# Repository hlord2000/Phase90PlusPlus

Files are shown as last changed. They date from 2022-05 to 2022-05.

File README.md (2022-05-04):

# This is a modified and extended Phase90 pedal, intended to fit into a [1590BB enclosure](https://lovemyswitches.com/1590bb-enclosure-bare-aluminum-powder-coat/). Enjoy.

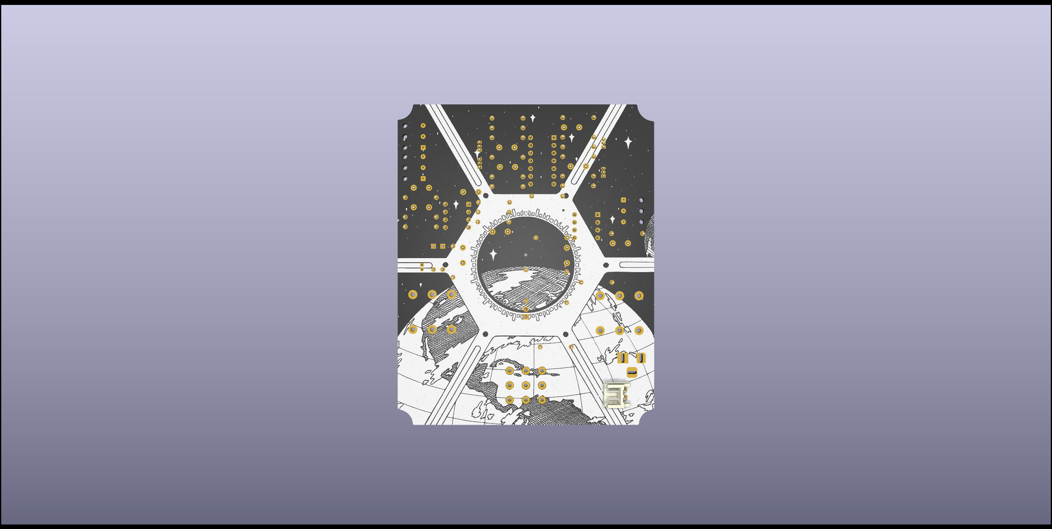
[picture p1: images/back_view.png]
Back View


## Interesting features
This pedal uses a software-controlled LFO [(StompLFO, a PIC microcontroller programmed by ElectricDruid)](https://electricdruid.net/product/stomplfo/) to generate a cool bunch of waveforms. The specific waveform is controlled with a potentiometer. An op-amp mixer is included on the output of the pedal, too, so that a musician can alter the mix of wet/dry tone. Finally, the traditional frequency potentiometer is included. This is a true bypass pedal.

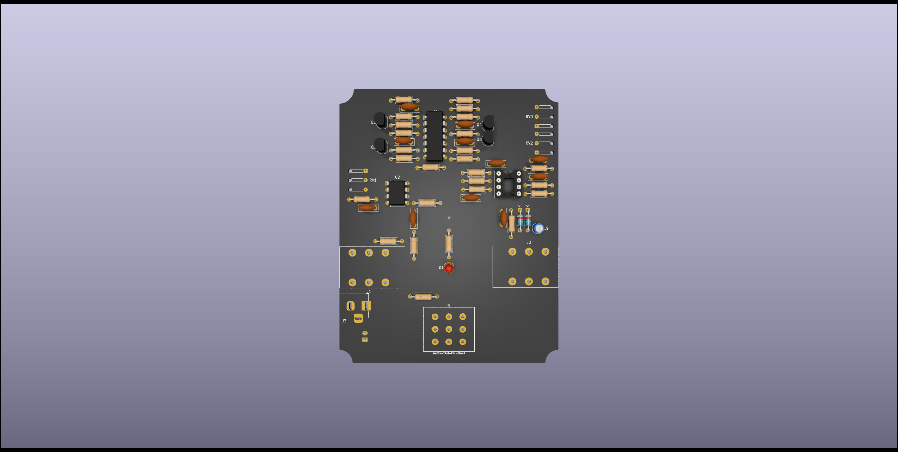
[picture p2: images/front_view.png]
Front View


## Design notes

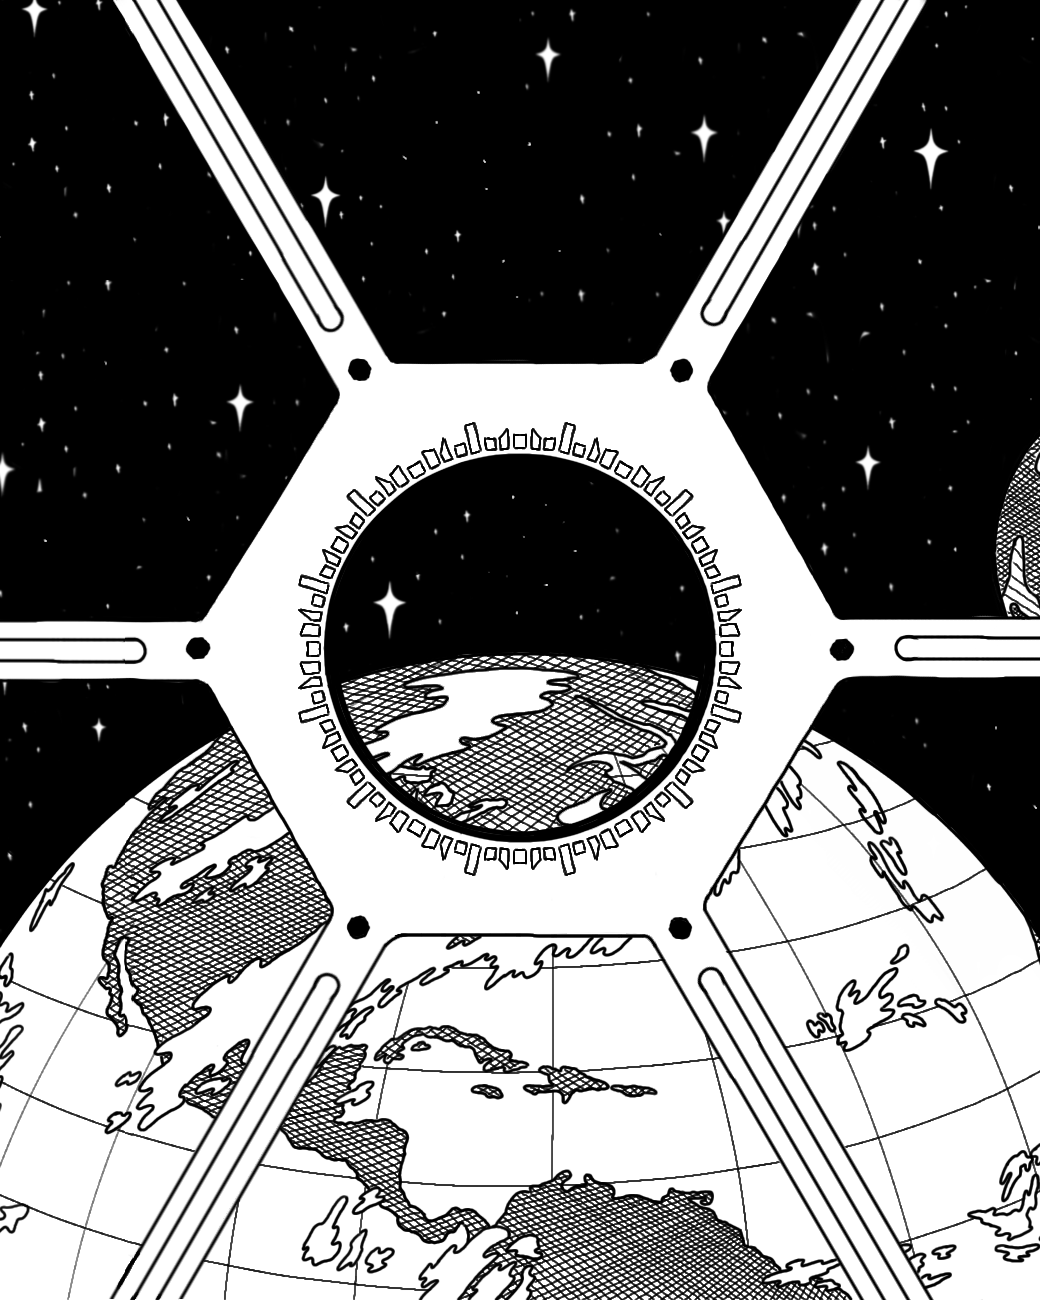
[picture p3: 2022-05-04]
images/art.png

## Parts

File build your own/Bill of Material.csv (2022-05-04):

Source: | C:\Users\Helmut Lord\Documents\Phase90++\phase90plusplus.kicad_sch
Date: | 5/4/2022 3:37:26 PM
Tool: | Eeschema (6.0.1)
Generator: | C:\Program Files\KiCad\6.0\bin\scripting\plugins/bom_csv_grouped_by_value_with_fp.py
Component Count: | 56
Ref | Qnty | Value | Cmp name | Footprint | Description | Vendor
BT1, | 1 | 9V DC | Battery_Cell | Connector_JST:JST_EH_S2B-EH_1x02_P2.50mm_Horizontal | Single-cell battery
C1, | 1 | 0.01u | C_Small | Capacitor_THT:C_Disc_D7.5mm_W2.5mm_P5.00mm | Unpolarized capacitor, small symbol
C2, C3, C4, C5, C6, C7, | 6 | 47n | C_Small | Capacitor_THT:C_Disc_D7.5mm_W2.5mm_P5.00mm | Unpolarized capacitor, small symbol
C8, | 1 | 4n7 | C_Small | Capacitor_THT:C_Disc_D7.5mm_W2.5mm_P5.00mm | Unpolarized capacitor, small symbol
C9, | 1 | 15u | C_Polarized_Small | Capacitor_THT:CP_Radial_D4.0mm_P1.50mm | Polarized capacitor, small symbol
C10, | 1 | 47nF | C_Small | Capacitor_THT:C_Disc_D7.5mm_W2.5mm_P5.00mm | Unpolarized capacitor, small symbol
C11, C12, | 2 | 100n | C_Small | Capacitor_THT:C_Disc_D7.5mm_W2.5mm_P5.00mm | Unpolarized capacitor, small symbol
D1, | 1 | LED | LED | LED_THT:LED_D3.0mm | Light emitting diode
D2, | 1 | 1N914 | 1N914 | Diode_THT:D_DO-35_SOD27_P7.62mm_Horizontal | 100V 0.3A Small Signal Fast Switching Diode, DO-35
D3, | 1 | Zener | D_Zener | Diode_THT:D_DO-35_SOD27_P7.62mm_Horizontal | Zener diode
J1, | 1 | InputJack | AudioJack3_Dual_Switch_1 | Connector_Audio:Jack_6.35mm_Neutrik_NRJ6HM-1_Horizontal | Audio Jack, Dual, 3 Poles (Stereo / TRS), Switched Poles (Normalling)
J2, | 1 | OutputJack | AudioJack3_Dual_Switch | Connector_Audio:Jack_6.35mm_Neutrik_NRJ6HM-1_Horizontal | Audio Jack, Dual, 3 Poles (Stereo / TRS), Switched Poles (Normalling)
J3, | 1 | Barrel_Jack_Switch | Barrel_Jack_Switch | Connector_BarrelJack:BarrelJack_Horizontal | DC Barrel Jack with an internal switch
LFO1, | 1 | STOMPLFO_DIP8 | STOMPLFO_DIP8 | Package_DIP:DIP-8_W7.62mm_Socket
Q1, Q2, Q3, Q4, | 4 | 2N7000 | BF245A | Package_TO_SOT_THT:TO-92_Inline | 50mA Id, 30V Vgs, N-Channel FET Transistor, TO-92
R1, R2, R3, R4, R6, R7, R8, R9, R21, R22, R23, R24, | 12 | 10K | R_Small_US | Resistor_THT:R_Axial_DIN0207_L6.3mm_D2.5mm_P10.16mm_Horizontal | Resistor, small US symbol
R5, R10, | 2 | 150K | R_Small_US | Resistor_THT:R_Axial_DIN0207_L6.3mm_D2.5mm_P10.16mm_Horizontal | Resistor, small US symbol
R11, R13, | 2 | 500k | R_Small_US | Resistor_THT:R_Axial_DIN0207_L6.3mm_D2.5mm_P10.16mm_Horizontal | Resistor, small US symbol
R12, | 1 | 500 | R_Small_US | Resistor_THT:R_Axial_DIN0207_L6.3mm_D2.5mm_P10.16mm_Horizontal | Resistor, small US symbol
R14, R15, R16, R17, | 4 | 24K | R_Small_US | Resistor_THT:R_Axial_DIN0207_L6.3mm_D2.5mm_P10.16mm_Horizontal | Resistor, small US symbol
R18, | 1 | 150k | R_Small_US | Resistor_THT:R_Axial_DIN0207_L6.3mm_D2.5mm_P10.16mm_Horizontal | Resistor, small US symbol
R19, | 1 | 370 | R_Small_US | Resistor_THT:R_Axial_DIN0207_L6.3mm_D2.5mm_P10.16mm_Horizontal | Resistor, small US symbol
R20, | 1 | 100K | R_Small_US | Resistor_THT:R_Axial_DIN0207_L6.3mm_D2.5mm_P10.16mm_Horizontal | Resistor, small US symbol
R25, R26, | 2 | 1K | R_Small_US | Resistor_THT:R_Axial_DIN0207_L6.3mm_D2.5mm_P10.16mm_Horizontal | Resistor, small US symbol
RV1, RV2, RV3, | 3 | 10k | R_Potentiometer_US | Connector_Wire:SolderWire-0.1sqmm_1x03_P3.6mm_D0.4mm_OD1mm_Relief | Potentiometer, US symbol
S1, | 1 | SWITCH-3PDT-PTH-STOMP | SWITCH-3PDT-PTH-STOMP | Switches:STOMP_SWITCH_3PDT | 3-Pole, Double-Throw (3PDT) Switch Three-pole, double-throw stomp switch. Drawn as three separate gates for schematic clarity. <h4>SparkFun Products</h4><ul><li>Used in <a href="https://www.sparkfun.com/products/13124">SparkFun Proto Pedal</a> (PRT-13124)</li></ul>
U1, | 1 | TL074 | TL074 | Package_DIP:DIP-14_W7.62mm | Quad Low-Noise JFET-Input Operational Amplifiers, DIP-14/SOIC-14
U2, | 1 | TL072 | TL072 | Package_DIP:DIP-8_W7.62mm | Dual Low-Noise JFET-Input Operational Amplifiers, DIP-8/SOIC-8

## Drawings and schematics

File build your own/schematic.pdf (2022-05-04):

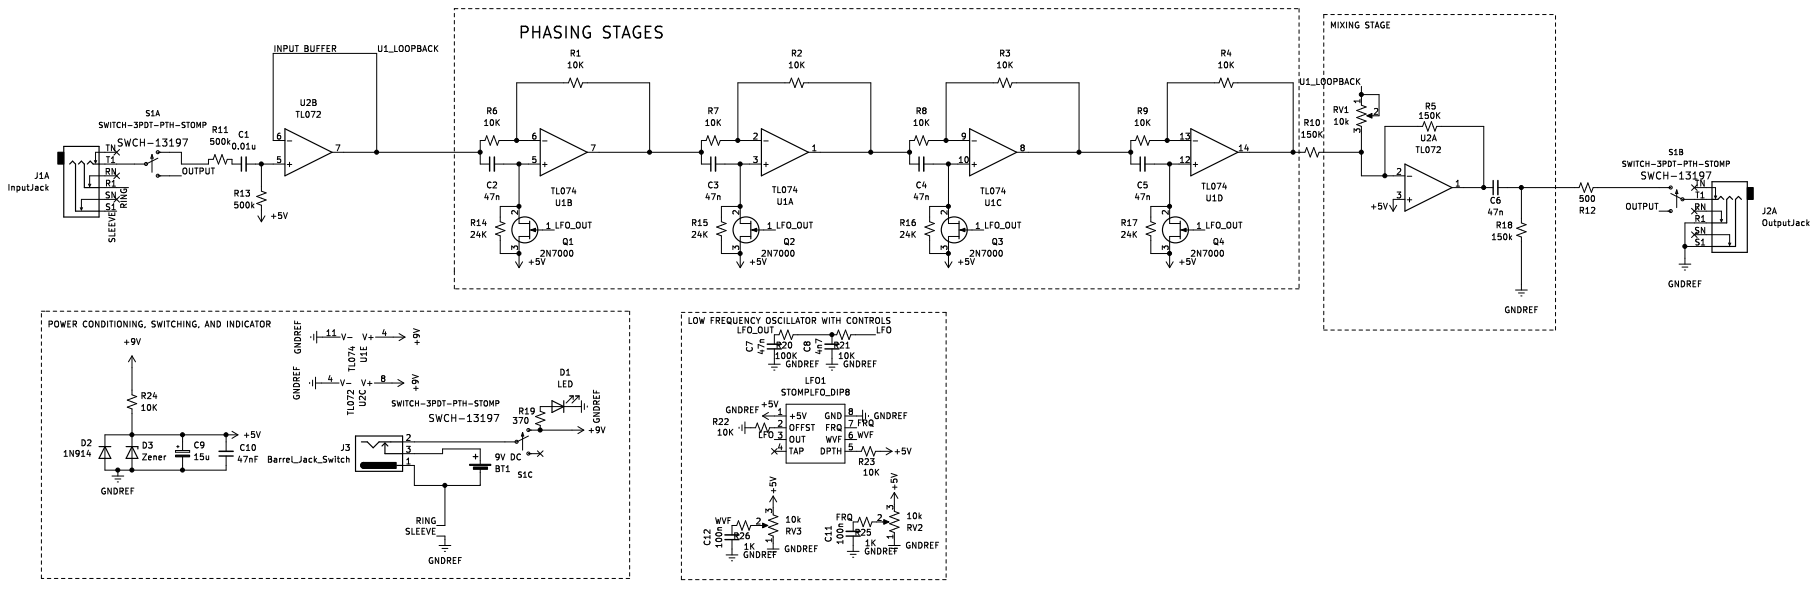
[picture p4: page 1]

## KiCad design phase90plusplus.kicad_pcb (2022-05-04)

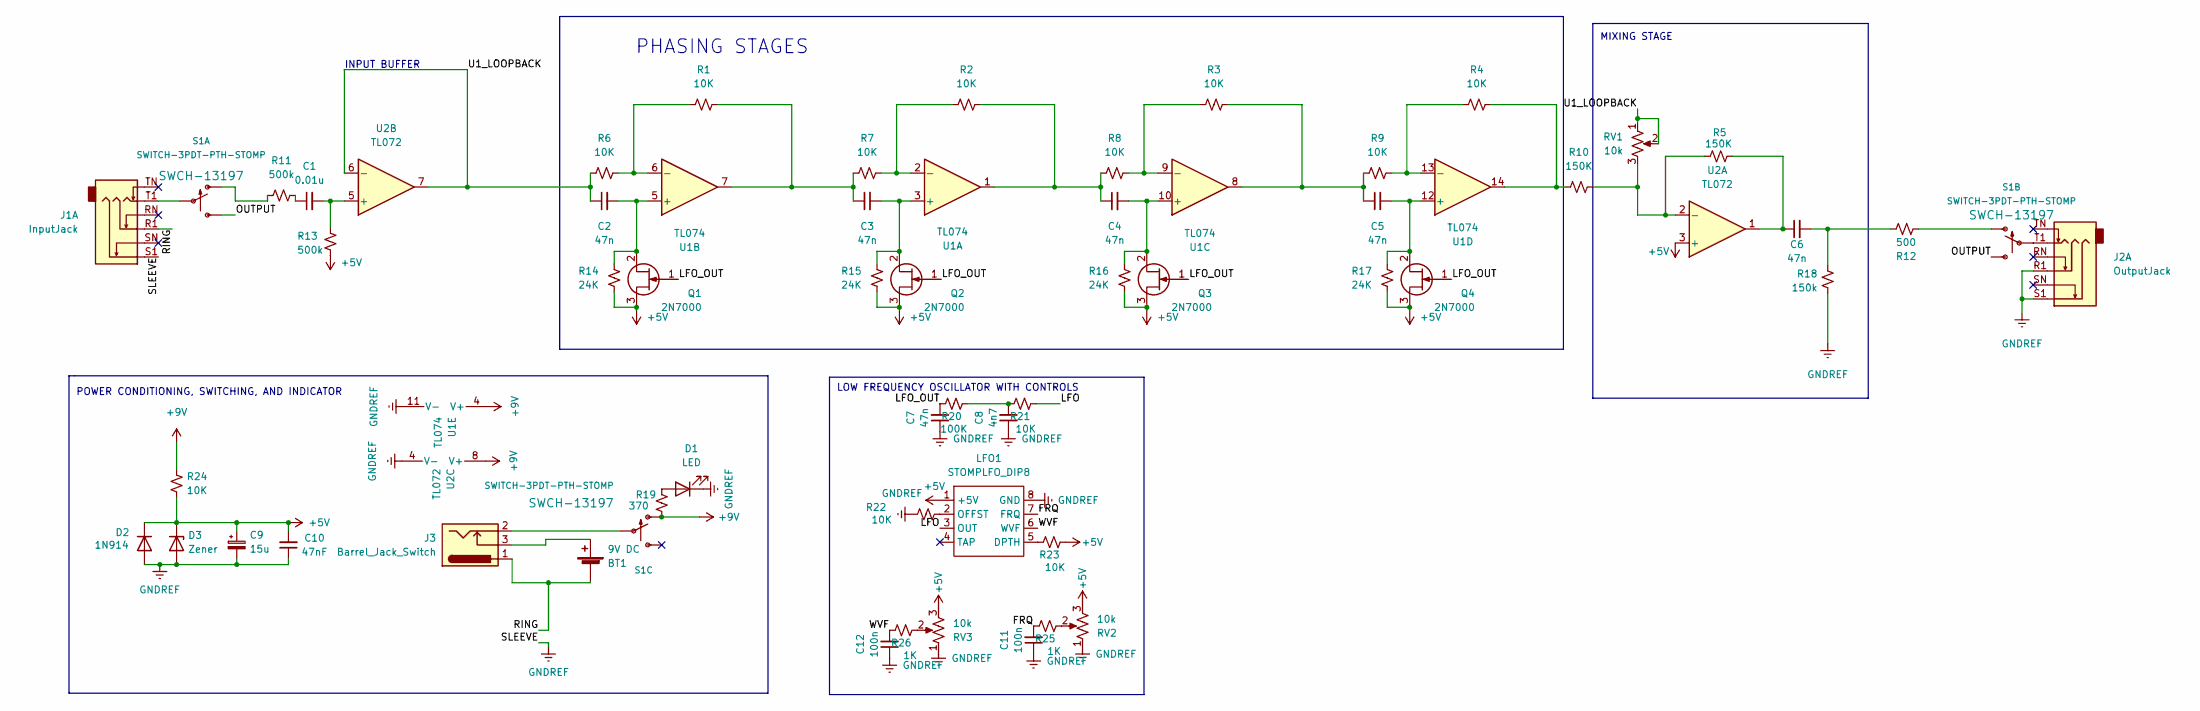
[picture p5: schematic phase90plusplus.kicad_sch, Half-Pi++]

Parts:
BT1: 9V DC; JST_EH_S2B-EH_1x02_P2.50mm_Horizontal
C1: 0.01u; C_Disc_D7.5mm_W2.5mm_P5.00mm
C2, C3, C4, C5, C6, C7: 47n; C_Disc_D7.5mm_W2.5mm_P5.00mm
C8: 4n7; C_Disc_D7.5mm_W2.5mm_P5.00mm
C9: 15u; CP_Radial_D4.0mm_P1.50mm
C10: 47nF; C_Disc_D7.5mm_W2.5mm_P5.00mm
C11, C12: 100n; C_Disc_D7.5mm_W2.5mm_P5.00mm
D1: LED; LED_D3.0mm
D2: 1N914; D_DO-35_SOD27_P7.62mm_Horizontal
D3: Zener; D_DO-35_SOD27_P7.62mm_Horizontal
J1: InputJack; Jack_6.35mm_Neutrik_NRJ6HM-1_Horizontal
J2: OutputJack; Jack_6.35mm_Neutrik_NRJ6HM-1_Horizontal
J3: Barrel_Jack_Switch; BarrelJack_Horizontal
LFO1: STOMPLFO_DIP8; DIP-8_W7.62mm_Socket
Q1, Q2, Q3, Q4: 2N7000; TO-92_Inline
R1, R2, R3, R4, R6, R7, R8, R9, R21, R22, R23, R24: 10K; R_Axial_DIN0207_L6.3mm_D2.5mm_P10.16mm_Horizontal
R5, R10: 150K; R_Axial_DIN0207_L6.3mm_D2.5mm_P10.16mm_Horizontal
R11, R13: 500k; R_Axial_DIN0207_L6.3mm_D2.5mm_P10.16mm_Horizontal
R12: 500; R_Axial_DIN0207_L6.3mm_D2.5mm_P10.16mm_Horizontal
R14, R15, R16, R17: 24K; R_Axial_DIN0207_L6.3mm_D2.5mm_P10.16mm_Horizontal
R18: 150k; R_Axial_DIN0207_L6.3mm_D2.5mm_P10.16mm_Horizontal
R19: 370; R_Axial_DIN0207_L6.3mm_D2.5mm_P10.16mm_Horizontal
R20: 100K; R_Axial_DIN0207_L6.3mm_D2.5mm_P10.16mm_Horizontal
R25, R26: 1K; R_Axial_DIN0207_L6.3mm_D2.5mm_P10.16mm_Horizontal
RV1, RV2, RV3: 10k; SolderWire-0.1sqmm_1x03_P3.6mm_D0.4mm_OD1mm_Relief
S1: SWITCH-3PDT-PTH-STOMP; STOMP_SWITCH_3PDT
U1: TL074; DIP-14_W7.62mm
U2: TL072; DIP-8_W7.62mm

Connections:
+5V: C9.1, C10.2, D2.1 (K), D3.1 (K), LFO1.1 (+5V), Q1.3 (D), Q2.3 (D), Q3.3 (D), Q4.3 (D), R13.1, R14.1, R15.1, R16.1, R17.1, R23.1, R24.2, RV2.3, RV3.3, U2.3 (+)
+9V: R19.1, R24.1, S1.P$7 (O), U1.4 (V+), U2.8 (V+)
/FRQ: C11.2, LFO1.7 (FRQ), R25.2
/LFO: LFO1.3 (OUT), R21.1
/LFO_OUT: C7.2, Q1.1 (G), Q2.1 (G), Q3.1 (G), Q4.1 (G), R20.2
/OUTPUT: S1.P$3 (S), S1.P$6 (S)
/RING: BT1.2 (-), J1.R1, J3.1
/U1_LOOPBACK: C2.1, R6.1, RV1.1, RV1.2, U2.6 (-), U2.7
/WVF: C12.2, LFO1.6 (WVF), R26.2
GNDREF: C7.1, C8.1, C9.2, C10.1, C11.1, C12.1, D1.1 (K), D2.2 (A), D3.2 (A), J1.S1, J2.R1, J2.S1, LFO1.8 (GND), R18.1, R22.2, RV2.1, RV3.1, U1.11 (V-), U2.4 (V-)
unnamed: BT1.1 (+), J3.3
unnamed: C1.1, R11.2
unnamed: C1.2, R13.2, U2.5 (+)
unnamed: C2.2, Q1.2 (S), R14.2, U1.5 (+)
unnamed: C3.1, R1.2, R7.1, U1.7
unnamed: C3.2, Q2.2 (S), R15.2, U1.3 (+)
unnamed: C4.1, R2.2, R8.1, U1.1
unnamed: C4.2, Q3.2 (S), R16.2, U1.10 (+)
unnamed: C5.1, R3.2, R9.1, U1.8
unnamed: C5.2, Q4.2 (S), R17.2, U1.12 (+)
unnamed: C6.1, R5.2, U2.1
unnamed: C6.2, R12.2, R18.2
unnamed: C8.2, R20.1, R21.2
unnamed: D1.2 (A), R19.2
unnamed: J1.T1, S1.P$2
unnamed: J2.T1, S1.P$5
unnamed: J3.2, S1.P$8
unnamed: LFO1.2 (OFFST), R22.1
unnamed: LFO1.5 (DPTH), R23.2
unnamed: R1.1, R6.2, U1.6 (-)
unnamed: R2.1, R7.2, U1.2 (-)
unnamed: R3.1, R8.2, U1.9 (-)
unnamed: R4.1, R9.2, U1.13 (-)
unnamed: R4.2, R10.1, U1.14
unnamed: R5.1, R10.2, RV1.3, U2.2 (-)
unnamed: R11.1, S1.P$1 (O)
unnamed: R12.1, S1.P$4 (O)
unnamed: R25.1, RV2.2
unnamed: R26.1, RV3.2

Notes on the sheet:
INPUT BUFFER
POWER CONDITIONING, SWITCHING, AND INDICATOR
LOW FREQUENCY OSCILLATOR WITH CONTROLS
MIXING STAGE
PHASING STAGES

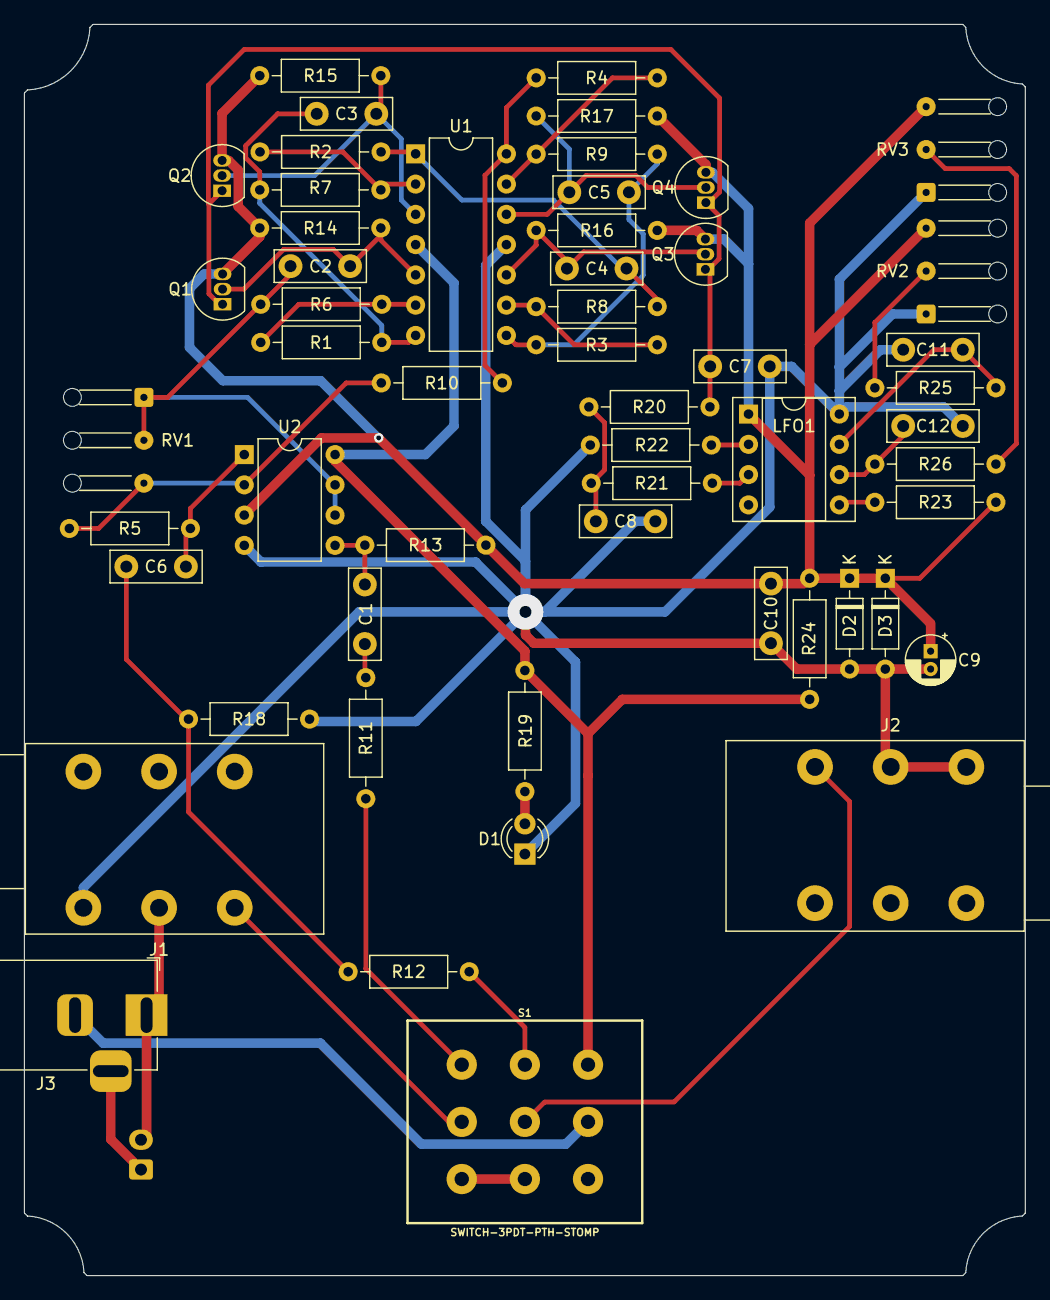
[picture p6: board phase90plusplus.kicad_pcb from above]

Board: 2 copper layers, 84.0 x 105.0 mm, 56 parts (1 on the bottom side), 39 nets.

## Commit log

2022-03-31 Initial commit.
    [phase90plusplus.kicad_pcb, phase90plusplus.kicad_sch]
2022-03-31 Initial revision of schematic.
2022-04-08 Hardware commit.
    [phase90plusplus.kicad_pcb, phase90plusplus.kicad_sch]
2022-04-29 Added libraries, initial routing and layout started. Schematic revised to add LED and power handling.
    [phase90plusplus.kicad_pcb, phase90plusplus.kicad_sch]
2022-05-04 Revision 1.0 complete.
    [Bill of Material.csv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]
